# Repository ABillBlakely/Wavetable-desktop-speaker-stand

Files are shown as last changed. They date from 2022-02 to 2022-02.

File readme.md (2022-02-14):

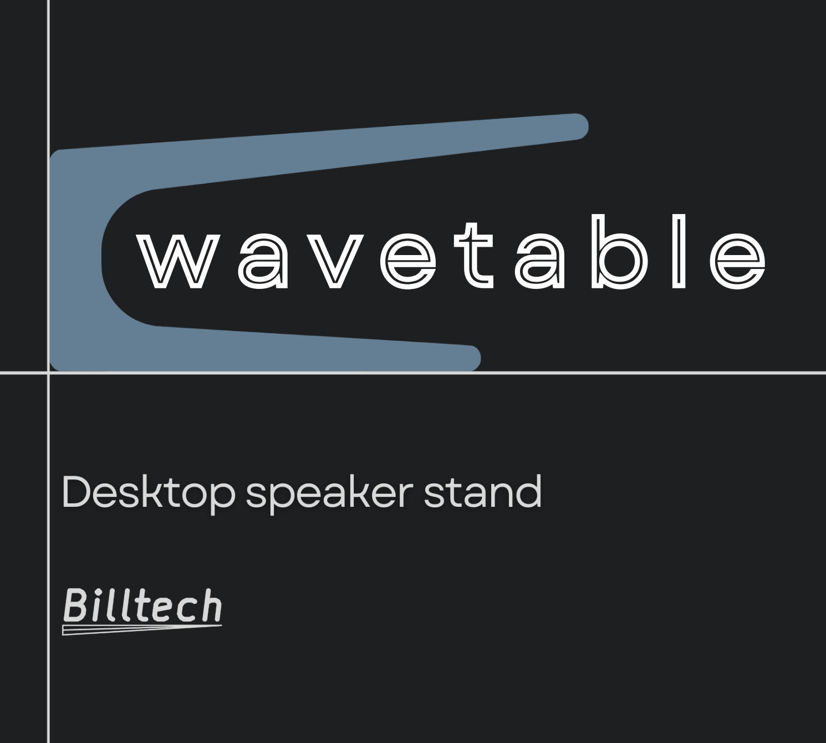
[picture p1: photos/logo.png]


# Overview.

Wavetable is a customizable, 3D printed speaker stand for your desktop.

Also see it at: https://www.prusaprinters.org/prints/127168-wavetable-desktop-speaker-stand

Adjustable for height, width, tilt angle and more. The cantilevered design allows you to partially reuse the negative space below your speaker. Despite the smooth curves and floating appearance, the stand is able hold the weight of large studio monitors easily.



Large or small, with or without a backstop, and highly configurable through the OpenSCAD parameters.

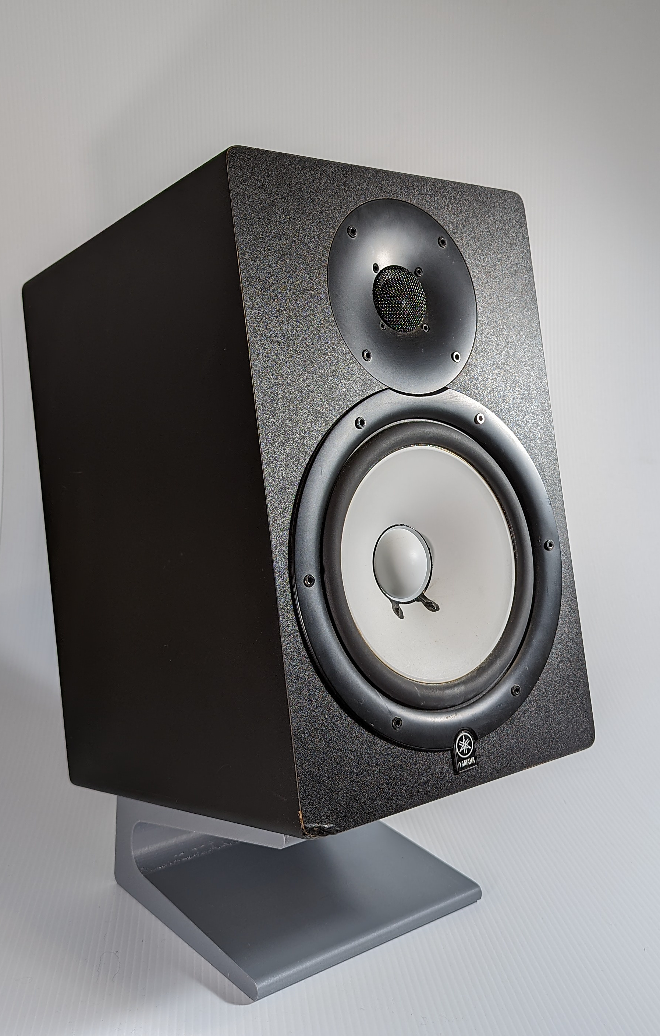
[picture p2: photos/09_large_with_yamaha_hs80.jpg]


Here the large version is holding the Yamaha HS80 Studio Monitor, weighing in at 11.3 kg (\~25 lbs). Mounting putty (blue-tack or similar) is useful for keeping speakers in place without a backstop, as the surface is somewhat slick when using PLA. I sometimes use it for the stand base and on the speaker so everything stays put.

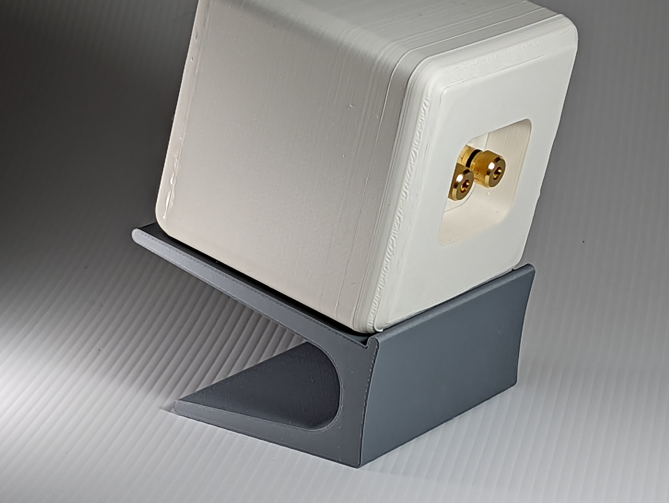
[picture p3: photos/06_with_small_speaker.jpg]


Pictured above is a prototype 3D printed speaker on the small stand with backstop.

# Modifications.

I am trying a new approach to modification with this model, through the use of the `params_<name>.scad` files.

Open up `wavetable_desktop_speaker_design.scad` in OpenSCAD and edit the import line to point to your desired params file. Open up the same params file in your text editor and take a look at the configurable parameters. Let the ASCII diagram guide you, let the comments fill in the rest.

A few preconfigured examples are provided that are similar to what is pictured here.

Saving will automatically update the main file showing your changes. This approach enables easy and flexible configuration like the OpenSCAD customizer, but has an advantage of easily saving multiple configurations. This opens the possibility of building a database for common speakers.

# Print Recommendations.

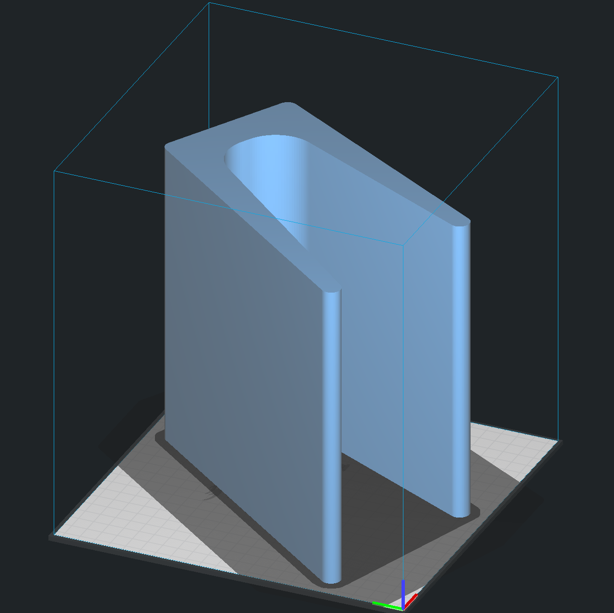
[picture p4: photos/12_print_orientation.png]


The `params_template_large.scad` results in a model the just barely fits on the platform of an Ender 3.

For all models it is recommended to use an orientation like above. Smaller models can be interwoven and printed two at once, although one at a time is preferred for best quality. The single profile makes for an easy print.

- Examples were printed in Overture Light Grey Matte PLA.
- Brim is advised to prevent warping of the thinner edges.
- 0.2mm layer height is good, 0.3mm layer height works well to reduce the print time especially for larger stands.
- 4 layers top and bottom for strength.
- 3 or 4 walls at 0.4 line width, for strength.
- 15 to 30% infill. Most patterns work well although I prefer cubic currently. Strength mostly comes from the walls and sides, not the infill.

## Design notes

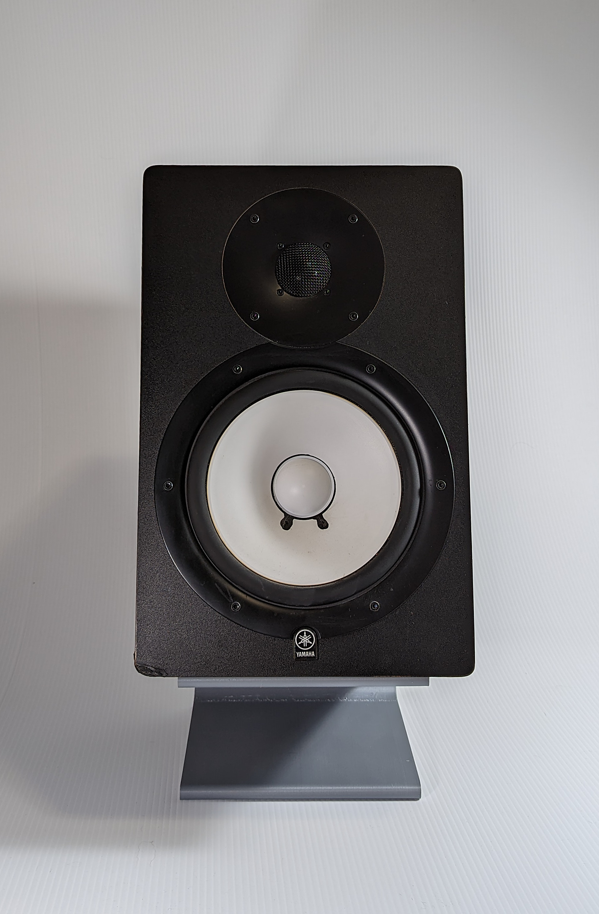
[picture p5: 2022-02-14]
photos/10_large_with_yamaha_hs80_front.jpg

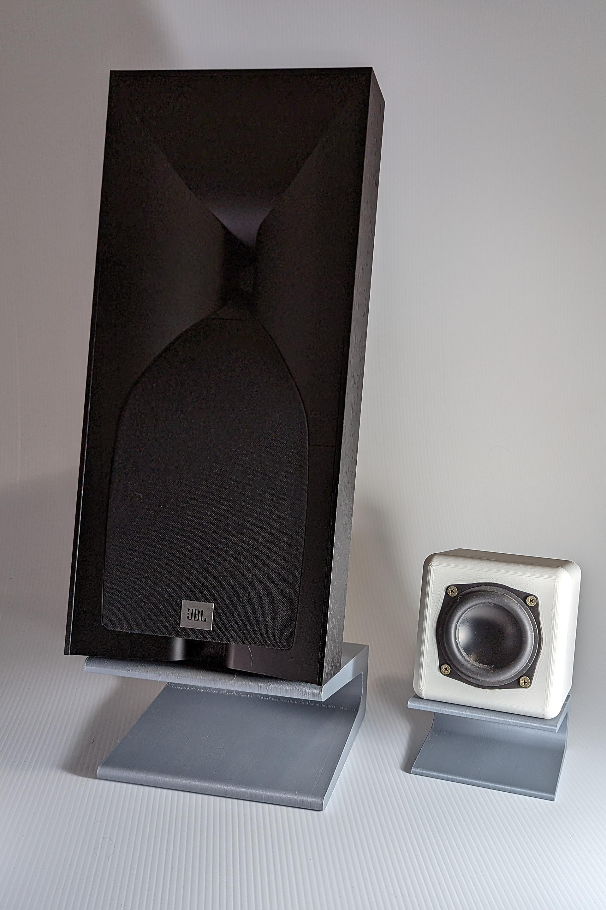
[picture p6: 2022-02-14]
photos/05_comparison_of_large_and_small.jpg

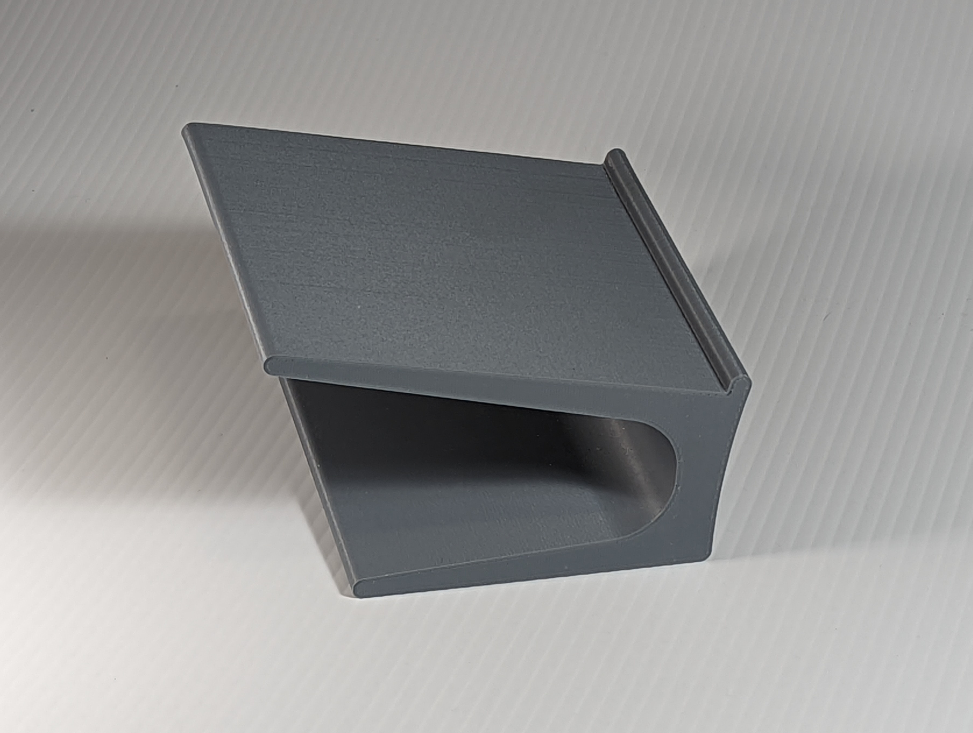
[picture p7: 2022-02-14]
photos/04_with_backstop.jpg

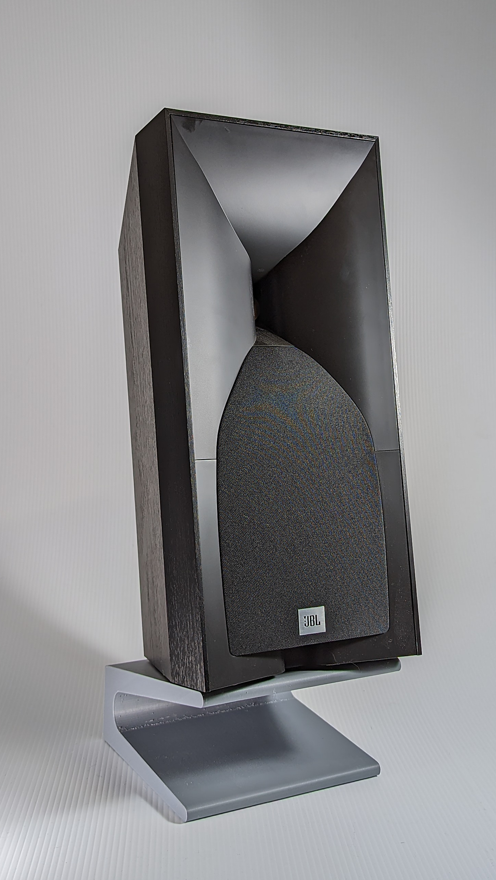
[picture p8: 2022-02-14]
photos/08_large_with_jbl_530.jpg

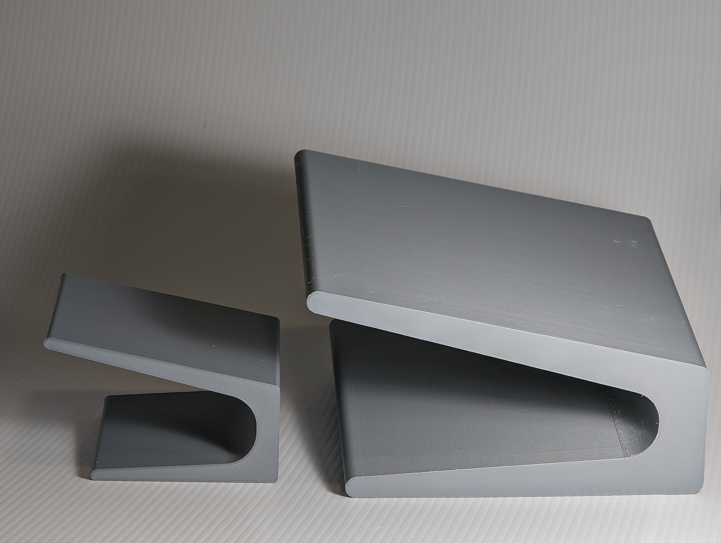
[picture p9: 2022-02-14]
photos/02_small_large.jpg

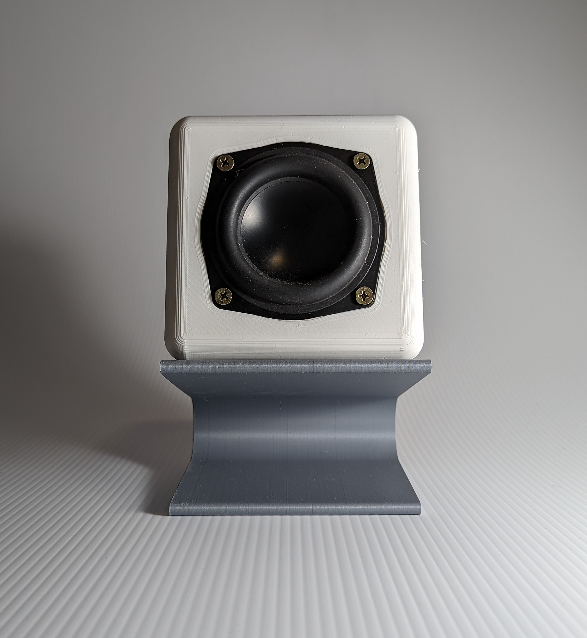
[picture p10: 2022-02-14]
photos/07_small_with_speaker_front.jpg

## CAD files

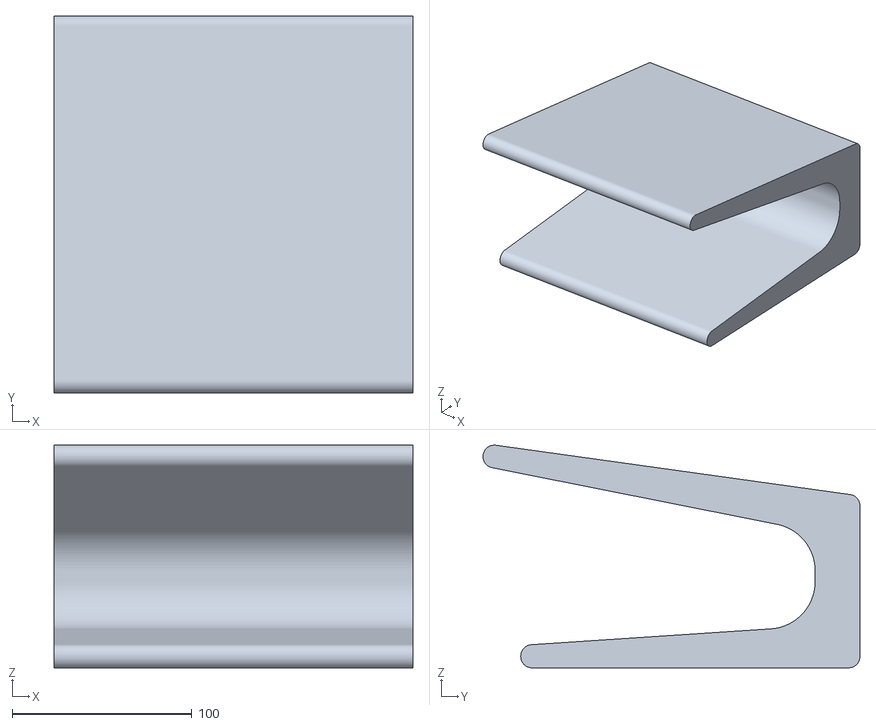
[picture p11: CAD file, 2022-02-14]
3d models/wavetable_desktop_speaker_stand_large.stl
200.0 x 210.0 x 124.1

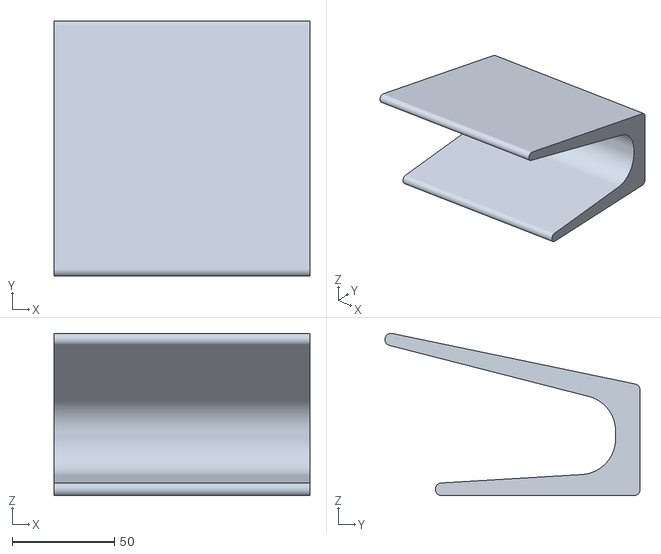
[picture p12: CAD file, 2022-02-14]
3d models/wavetable_desktop_speaker_stand_small.stl
125.0 x 124.6 x 79.2

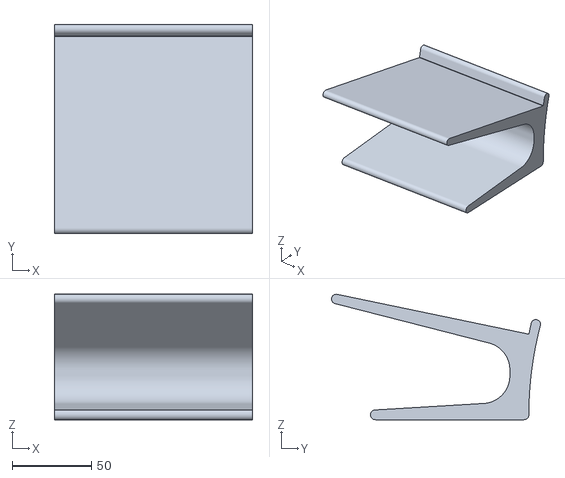
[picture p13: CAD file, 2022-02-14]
3d models/wavetable_desktop_speaker_stand_small_with_backstop.stl
125.0 x 132.0 x 79.2

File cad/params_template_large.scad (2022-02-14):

// Settings file for wavetable_desktop_speaker_stand.scad
// Model: Template
// Year created: 2022

// ASCII diagram of most dimensions:
//
//                    |
//                    |<-._  angle
//                    |    \
//                    |     |      top_depth   ___________---------->/
//                    |    _v________----------                     /
//              /<---------                                        /
//             /                                     ___________   _____
//            /                  __________----------           )    ^
//       \   __________----------                               /    |
//      /   /                                                  /     |
//   width /                                     ___________  /      |
//    /   /                  __________----------       ____)/       |
//   \   /__________----------               ______------            |
//       /                    _______--------                        |
//      |       ______-------                                     height
//      |      /   \__________                                       |
//      |     /    /          -----------____________                |
//      |    (    /                                  )               |
//      |     \  /                                   /               |
//      |      \/__________                         /                |
//      |                  ----------____________  /                 |
//       \_______________________________________)/                __v__
//
//      |                                         |
//      |                                         |
//      |<--------------bottom depth------------->|
//

// thickness is best thought of as overall 'chunkiness.'
// technically the minimum thickness of the back and thickness of top and bottom where they meet the back.
// The leading edges of the top and bottom will taper out to about 1/2 of the thickness.
thickness = 25;

// width of the stand.
width = 200;

//height from flat surface to front edge:
height = 125;

// top_depth is measured along the top surface of the stand, it should be similar to the depth of your speaker.
top_depth = 210;

// The bottom platform can be shorter than the top, values from 0.8 to 1.0 work well with larger values being more stable.
bottom_depth = 0.9*top_depth;

// tilt back angle of the top surface. Depending on thickness, infill percent, speaker weight, the stand could bend a little.
// recommended value is < 12 degrees
angle = 8;

// Include a lip at the back to prevent the speaker from sliding backwards.
// lip dimensions are derived from `thickness`
// the stop is in addition to the speaker depth so no changes to `top_depth` should be required.
include_stop = false;
// adjustable height, but must be at least 1/2 the thickness because of the half round that is added.
stop_height = 12.5;

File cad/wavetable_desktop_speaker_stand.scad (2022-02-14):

// To customize this model, it is reccomended to create a copy of the params_template.scad file.
include <params_template_small.scad>
// include <params_template_small_with_backstop.scad>
// include <params_template_large.scad>

finalize();

$fn=100;

// Calculated values, not recommended to change.
tapered_thickness = thickness / 2;
back_height = height - top_depth * sin(angle);
in_round = (back_height + 2 * thickness * (sin(angle) - 1)) / 2;
out_round = tapered_thickness / 2;
// Stop height moved to params file:
// stop_height = thickness / 2;

// For debug, access to each submodule:
// backstop();
// form();
// profile();
// base();
// back();
// top();


module finalize(){
    // This module gets the final elements of the stand including
    // adding the backstop if set to true. This module should be
    // called to create the complete model.

    rotate([90, 0, -90])
    translate([0,0,width/2])

    if (include_stop){
        union(){
            speaker_stand();
            backstop();
        }
    }
    else{
        speaker_stand();
    }
}
module backstop(){

    // This module creates the backstop which is optionally added to the stand.
    // It also adds a concavity to the backside which serves to balance the
    // addtional thickness caused by adding the backstop.

    // Crucial coordinates of the new back for calculating the backstop concavity
    Ax = (stop_height - out_round) * sin(angle) + 2 * out_round * cos(angle);
    Ay = (stop_height - out_round) * cos(angle) + back_height - 2 * out_round * sin(angle);
    Bx = 0;
    By = out_round;

    // We need to determine a circle such that the new (flat) rear edge of the backstop creates
    // a chord of the circle that will carve out the concave back.

    // Determine the chord length (equal to back length) and angle (equal to back angle):
    chord_length = sqrt((Ax - Bx) ^ 2 + (Ay - By) ^ 2);
    back_angle = asin((Ay - By)/chord_length);

    // From these two parameters we can calculate the correct radius with trig.
    rear_concavity_radius = chord_length / 2 / sin (90 - back_angle);
    echo(rear_concavity_radius);

    rotate([0,180, 0])
    linear_extrude(width, center=true){
        union(){
            difference(){
                union(){
                    // build main body of what will become the backstop,
                    // this must extend into the existing profile to cover the rounding there.
                    polygon(points=[
                        [Bx, By],
                        [Bx - thickness, By],
                        [Bx - thickness, back_height + thickness * sin(angle)],
                        [0, back_height],
                        [(stop_height - out_round)*sin(angle), (stop_height - out_round) * cos(angle) + back_height],
                        [Ax, Ay],
                        ]
                    );
                    // add small interior corner radius to soften transition into the backstop.
                    transition_radius = 0.5;
                    // 0.003 is a hacky fix due to a gap that opens at some tilt angles
                    translate([0, back_height-0.003])
                    rotate([0,0,-90 - angle])
                    translate([-transition_radius, -transition_radius])
                    difference(){
                        square(transition_radius);
                        circle(r=transition_radius);
                    }
                }
                // carve out the rear concavity.
                translate([rear_concavity_radius, out_round])
                circle(r=rear_concavity_radius, $fn=500);
            }
            // add circle to top of backstop to create round edge.
            translate([(stop_height - out_round)*sin(angle) + out_round * cos(angle), (stop_height - out_round) * cos(angle) + back_height - out_round * sin(angle)])
            circle(r=out_round);
        }
    }
}

module speaker_stand(){
    // This module extrudes the profile() to create the
    // solid model of the stand excludin the backstop.
    linear_extrude(width, center = true)
    profile();
}

module profile(){
    // This module composes the polygons from base(), back() and top() and
    // adds the concave and convex rounding except in the backstop.

    // form concave corners
    offset(r=-in_round, chamfer=true)
    offset(r=in_round, chamfer=true)

    // form convex corners
    offset(r=out_round, chamfer=true)
    offset(r=-out_round, chamfer=true)
    union(){
        back();
        top();
        base();
    }
}

module base(){
    // This module draws the basic shape of the base,
    // tapering to 1/2 the thickness.
    polygon(points=[
            [0,0],
            [0, thickness],
            [bottom_depth, tapered_thickness],
            [bottom_depth, 0]
        ]
    );
}

module back(){
    // This module draws the basic shape of the back
    square([thickness, back_height]);
}

module top(){
    // This module draws the basic shape of the top angled back
    // by the defined angle, and tapering to 1/2 the thickness.
    rise_from_angle = top_depth * sin(angle);
    translate([0, back_height-thickness])
    polygon(points=[
            [0,0],
            [0, thickness],
            [top_depth, thickness + rise_from_angle],
            [top_depth, thickness - tapered_thickness + rise_from_angle]
        ]
    );
}

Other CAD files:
cad/params_template_small.scad
cad/params_template_small_with_backstop.scad
